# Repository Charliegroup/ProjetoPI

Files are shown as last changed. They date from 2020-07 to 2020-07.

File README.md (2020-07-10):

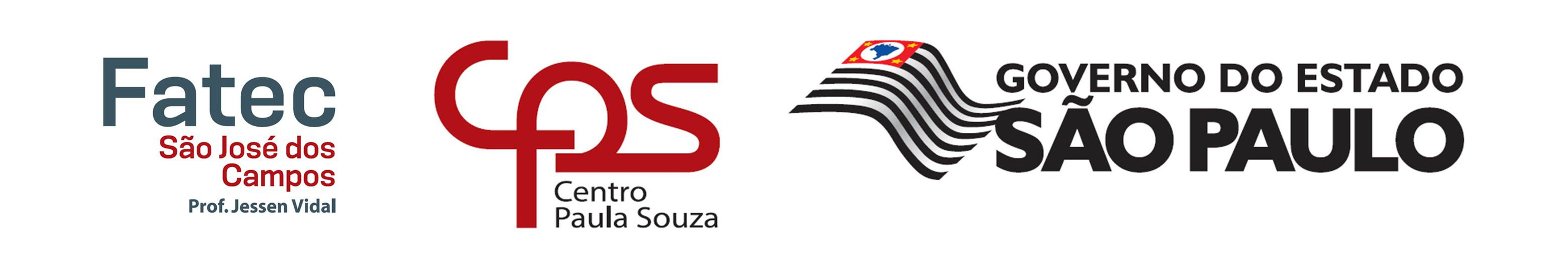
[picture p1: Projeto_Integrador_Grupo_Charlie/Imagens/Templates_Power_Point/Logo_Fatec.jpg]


# Projeto Integrador 4.0 - Fatec São José dos Campos

# - 📁 Descrição das Pastas

* ### Apresentações 
             ➥ Contém as apresentações desenvolvidas pelo grupo;
* ### Atas 
             ➥ Contém as ATAS desenvolvidas durante o projeto;
* ### CAD 
             ➥ Contém os projetos 3D e 2D das peças feitas no CATIA V5;
* ### Cálculos 
             ➥ Contém os cálculos aplicados e utilizados no projeto;
* ### Documentos
             ➥ Contém documentações importantes do projeto;
* ### Imagens
             ➥ Contém todas imagens e templates referentes ao projeto;

# - 📚 Disciplinas integradas

* ### Projeto Integrador 
  Prof. Alexandre Zaramela
* ### Familiarização Aeronáutica 
  Prof. Felix Arlindo Strottmann
* ### Desenho Técnico de Aeronaves
  Profª. Fabiana Eloisa Passador
* ### Informática Aplicada a Aeronáutica
  Prof. Fabrício Galende Marques de Carvalho
* ### Inglês
  Prof. Nilo Jeronimo Vieira
* ### Comunicação Oral e Escrita
  Profª. Maria Goreti Lopes Cepinho
* ### Cálculo Aplicado a Aeronáutica
  Profª. Danielle Cristina de Morais Amorim
* ### Física e Quimica Aplicada a Aeronáutica
  Profª. Danielle Cristina de Morais Amorim
* ### Meio Ambiente, Saude e Seguranca no Trabalho
  Prof. Joares Lidovino dos Reis
* ### Legislação Social Aplicada a Aeronáutica
  Profª. Ana Cecília Rodrigues Medeiros

# - 👥 Grupo: 

* ### Ricardo Donizeti dos Santos - Líder/ Projetista
* ### Paulo Rafael Ribeiro - Vice Líder/ Anotador
* ### Thiago dos Reis Souza - Gestor/ Atas e diário e bordo

# - ✈ Objetivo:

Desenvolver uma ferramenta para desmontagem e/ou instalação do Cilindro do motor Turbo Hélice IO-360-N1A, da Aeronave Embraer EMB-120.
⠀⠀⠀⠀⠀⠀⠀⠀⠀⠀⠀⠀⠀⠀⠀⠀⠀⠀⠀⠀⠀⠀⠀⠀⠀⠀⠀⠀⠀⠀⠀⠀⠀⠀⠀⠀⠀⠀⠀⠀⠀⠀⠀⠀⠀⠀⠀⠀⠀⠀⠀⠀⠀⠀⠀⠀⠀⠀⠀⠀⠀⠀⠀⠀⠀⠀⠀⠀⠀⠀⠀⠀⠀⠀⠀⠀⠀⠀⠀⠀⠀⠀⠀⠀⠀⠀⠀⠀⠀⠀⠀⠀⠀⠀
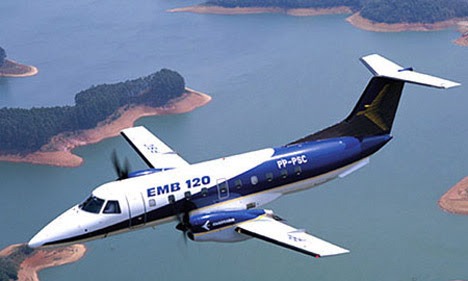
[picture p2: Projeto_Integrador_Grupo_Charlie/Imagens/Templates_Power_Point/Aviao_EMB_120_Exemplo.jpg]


# - 🔧 Ferramentas:
⠀⠀⠀⠀⠀⠀⠀⠀⠀⠀⠀⠀⠀⠀⠀⠀⠀⠀⠀⠀⠀⠀⠀⠀⠀⠀⠀⠀⠀⠀⠀⠀⠀⠀⠀⠀⠀⠀⠀⠀⠀⠀⠀⠀⠀⠀⠀⠀⠀⠀⠀⠀⠀⠀⠀⠀⠀⠀⠀⠀⠀⠀⠀⠀⠀⠀⠀⠀⠀⠀⠀⠀⠀⠀⠀⠀⠀⠀⠀⠀⠀⠀⠀⠀⠀⠀⠀⠀⠀⠀⠀⠀⠀⠀
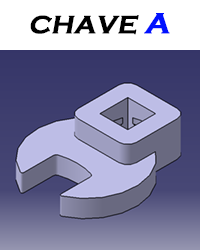
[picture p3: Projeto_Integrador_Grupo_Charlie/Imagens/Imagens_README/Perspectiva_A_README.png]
⠀⠀⠀⠀⠀⠀⠀⠀⠀
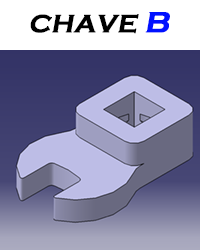
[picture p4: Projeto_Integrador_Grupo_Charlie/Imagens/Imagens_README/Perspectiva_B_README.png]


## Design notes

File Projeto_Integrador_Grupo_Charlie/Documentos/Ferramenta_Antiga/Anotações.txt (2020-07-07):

Tem que o termostato entre 90 e 130 graus

Ferramentas padrões

antes de desmontar tem que despressurizar (retirar a graxa ou o oleo), removendo as valvulas 3/10 e 3/20

remover os tubos flexiveis 2/20 e 2/30

remover os tubos rigidos 3/100

afroxar a porca 3/80 para remover a pressao e remover o cotovelo 3/90

afroxar a porca 3/150 para remover a junção 3/140

remover o tubo de suporte 3/110

afroxar os 4 parafusos 3/120

mantenha as 4 arruelas 3/130

mantenha a abraçadeira 3/110 e (rolamento, cilindro) 3/160

remover separador 3/200

afroxar a porca 3/210

manter arruela 3/220 o pino 3/230 manter equipado o rolamento 3/170

remover as duas buxas 3/190(buxas precisam ser desmontadas numa temperatuxa maxima de 100º)

		Como retirar esta na pagina 301

B ----- 

remover o descarregador estatico 3/590

	remover parafuso 3/600 manter as arruelas 3/6i0 e depois remover o descarregador estatico
	
C -----

remover o "Arm torque" 3/460

	remover "fita" 3/400
		remover as 6 porcas 3/480 e o tubo 3/410, deixar a 6 arruelas 3/490 e as 3/420
		remover os 4 "collars" 3/440 e deixar os 6 parafusos 3/500, 3/510 e 3/450
		deixar os 4 flanger 3/430 e o bonding strip 3/400
	Remover com a ferramenta 50381 os dois pinos 3/520 e 3/530 segurando o "holding the arm torque"

D ----- 

desmontar arm torque

	remover o separador 5/100, destravar e remover a porca 5/110 e mantenha loking whaser 5/120 e arruela de ajuste 5/130
	usar a dural drift e um martelo para remover o pino 5/140
	separar as duas metades do "arm torque" 5/10 e 5/50 e manter a ball joint cage 5/160 e as duas metades da ball joint 5/180
	em cima da arm torque remover as porcas 3/550 e mantenha  as duas arruelas 3/560 e 3/570 e os parafusos 3/580. Libere o tipe guide 3/540

remover as seis buchas 5/30, 5/40 e 5/70 e a ball joint cage 5/80 (figura 302)
	Desmontar numa temperatura de 100ºC e evitar impacto pois pode danificar
	- duas buchas 5/40 usar dural drif 
	- as 4 buchas 5/30 e 5/70 e ball joint cage 5/80 usando o dural tapered drift
	
	PAGINA 304

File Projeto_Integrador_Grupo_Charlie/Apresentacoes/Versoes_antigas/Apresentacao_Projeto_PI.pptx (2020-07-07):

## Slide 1

FATEC SJC

Prof. Cliente: Felix Strottmann
Prof. Orientador: Alexandre Zaramela

Projeto integrador transversal:

Nomes dos integrantes:

• PAULO RAFAEL
• RICARDO DONIZETI
• THIAGO REIS

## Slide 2

FERRAMENTA

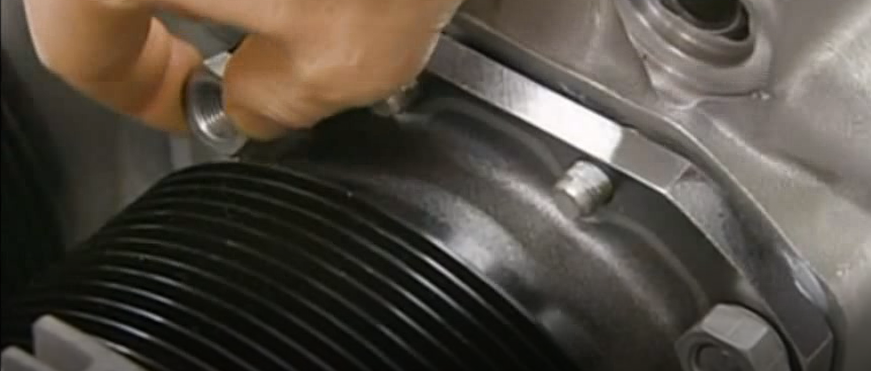
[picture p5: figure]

Soquete para Torquímetro

- Montagem do Piston Ring Compressor ( Fixação da base do cilindro).
- Aperto de porca

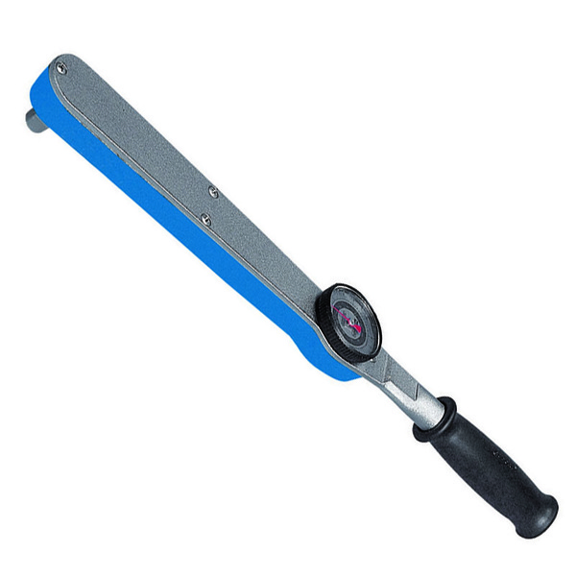
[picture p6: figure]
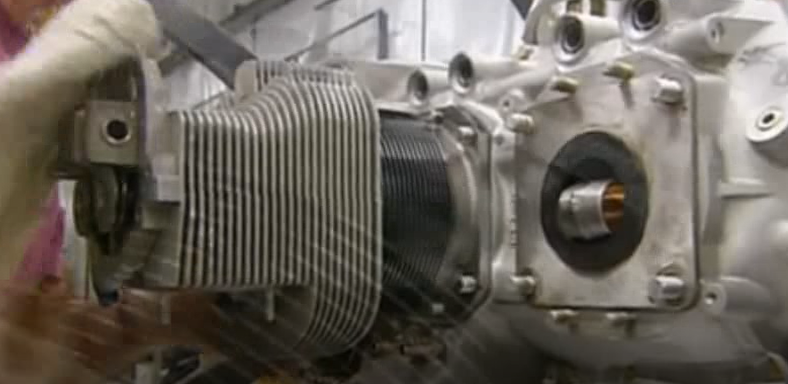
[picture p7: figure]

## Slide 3

COMPARAÇÕES

Primeiro desenho apresentado

Ferramenta proposta

Croqui atual

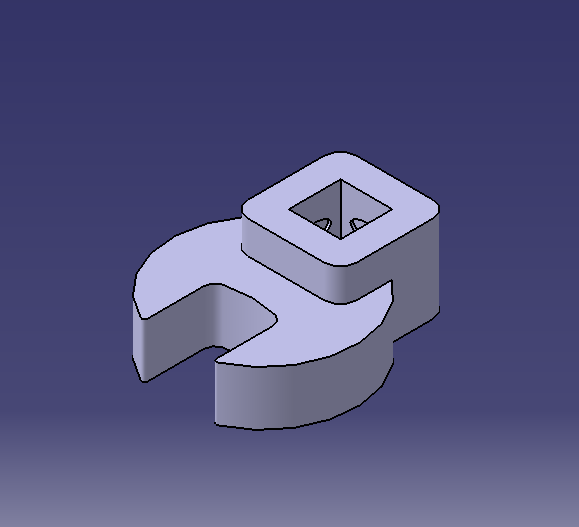
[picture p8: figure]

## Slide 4

COTAS

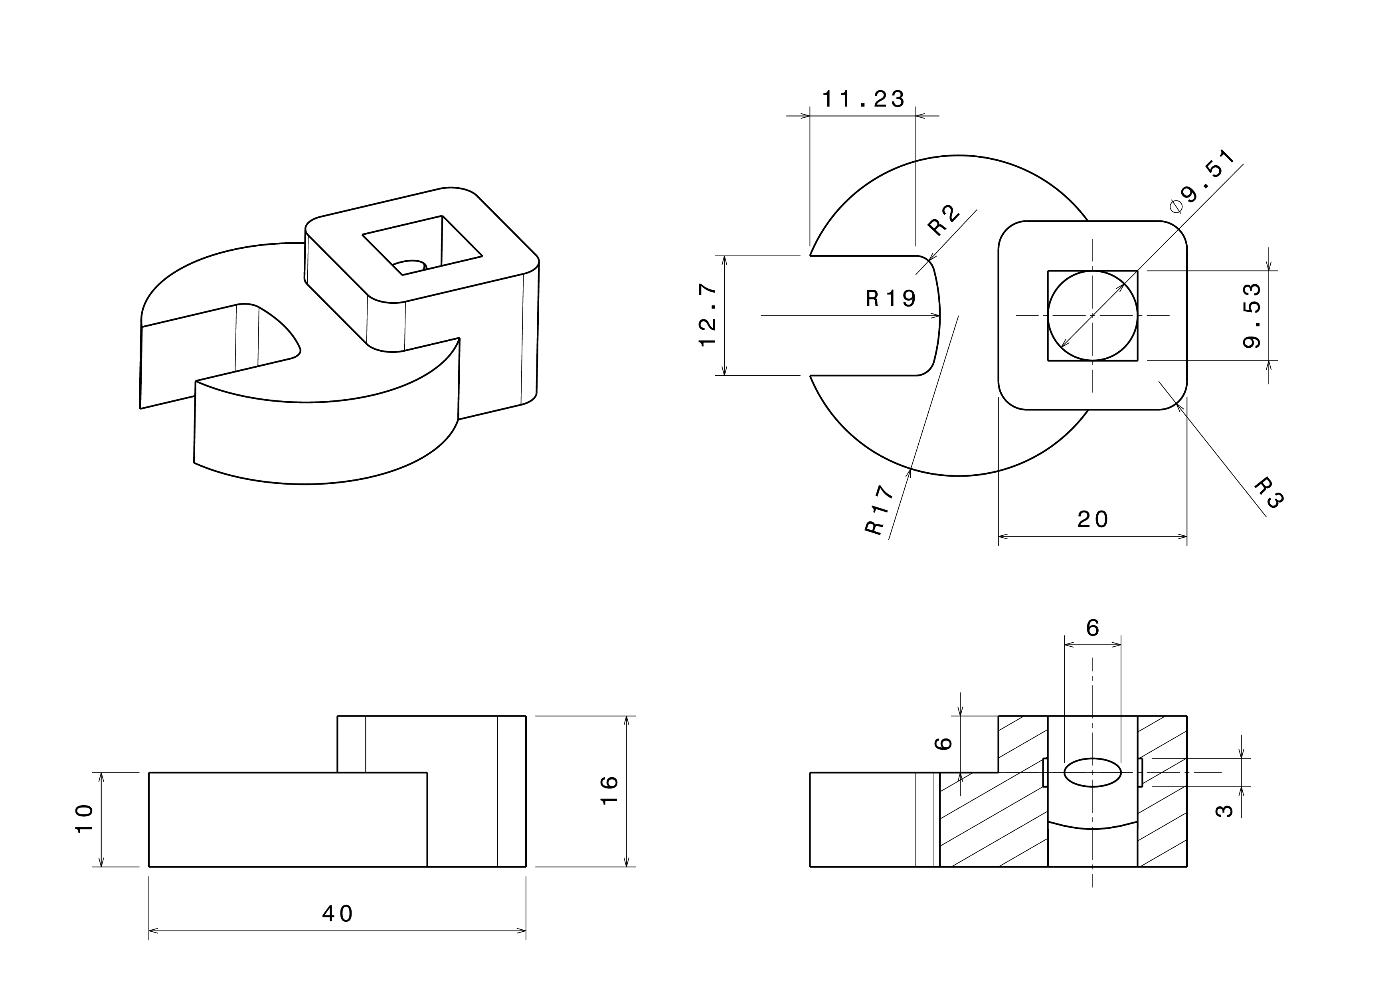
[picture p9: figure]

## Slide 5

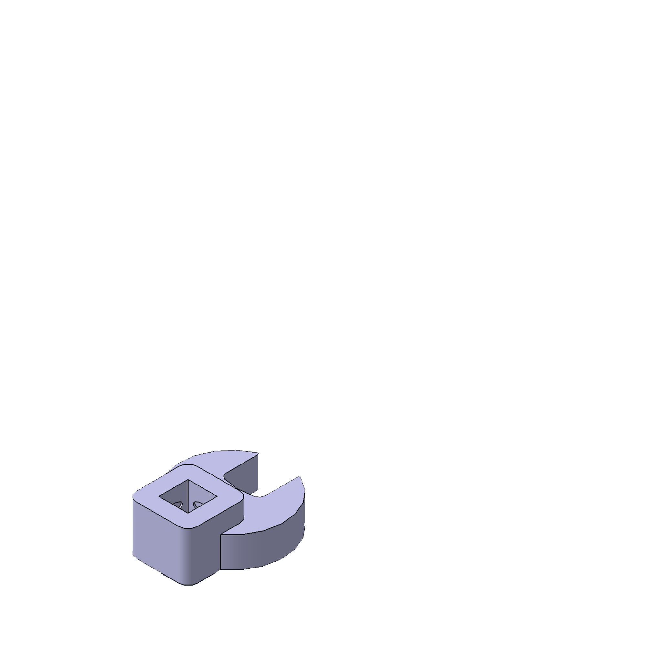
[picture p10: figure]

FERRAMENTA EM PERSPECTIVA

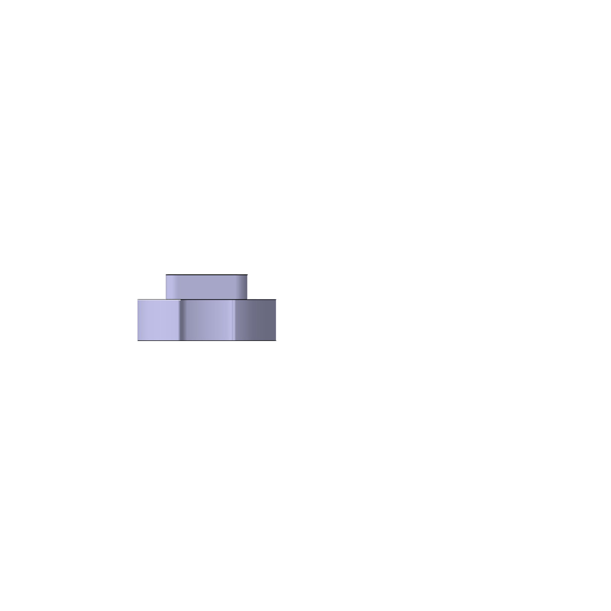
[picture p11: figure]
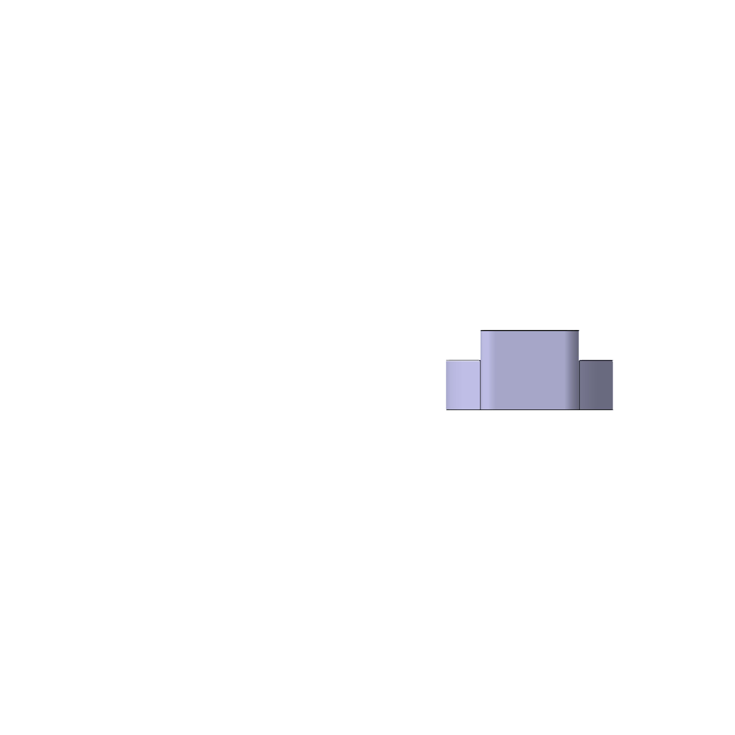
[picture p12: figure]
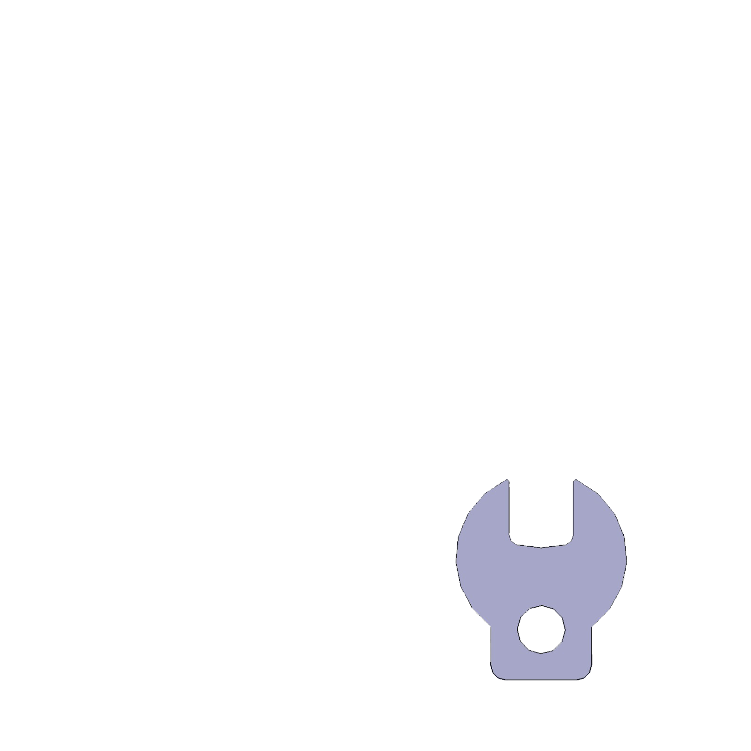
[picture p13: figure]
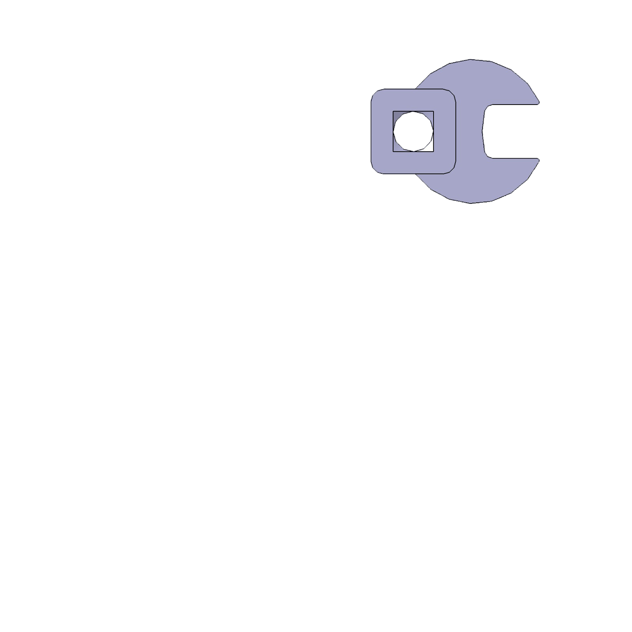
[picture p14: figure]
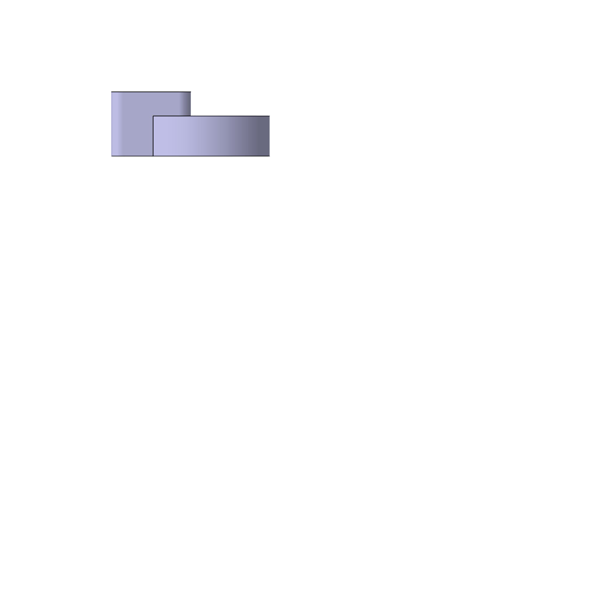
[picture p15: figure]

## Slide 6

CÁLCULO DE TENSÃO DE
CISALHAMENTO

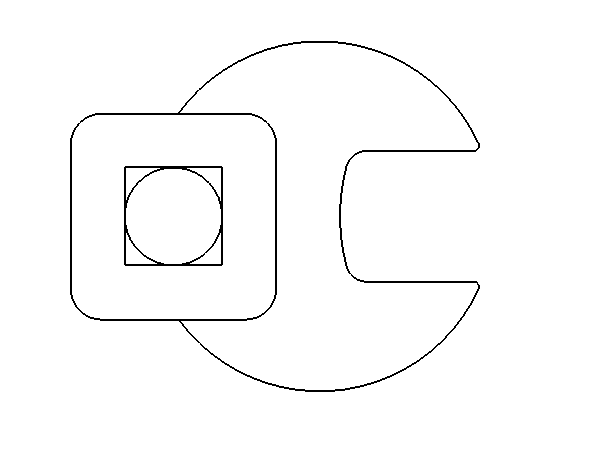
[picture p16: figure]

Força: 67.8 Nm

[Área: 10x

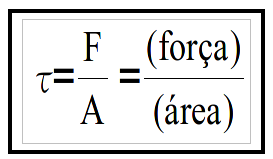
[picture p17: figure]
MINHA CIÊNCIA É FARMACÊUTICA: REOLOGIA: Noções Básicas

T = Torque (Nm)

t = Tensão (N/mm²)

F = Força (N)

A = Área (m²)

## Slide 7

MARGEM DE SEGURANÇA

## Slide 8

PROPRIEDADES “MATERIAL”

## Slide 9

REFERÊNCIAS

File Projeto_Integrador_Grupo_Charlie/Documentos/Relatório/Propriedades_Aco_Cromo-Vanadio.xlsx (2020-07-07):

 | Propriedades
Densidade (×1000 kg/m3) |  | 7.7-8.03
Coeficiente de Poisson |  | 0.27-0.30
Módulo de Elasticidade (GPa) |  | 190-210
Resistência à Tração (Mpa) |  | 670
Tensão de Escoamento (Mpa) |  | 415
Alongamento (%) |  | 23.0
Área de Redução (%) |  | 48.4
Dureza (HB) |  | 197
Força de Impacto (J) |  | 27.4

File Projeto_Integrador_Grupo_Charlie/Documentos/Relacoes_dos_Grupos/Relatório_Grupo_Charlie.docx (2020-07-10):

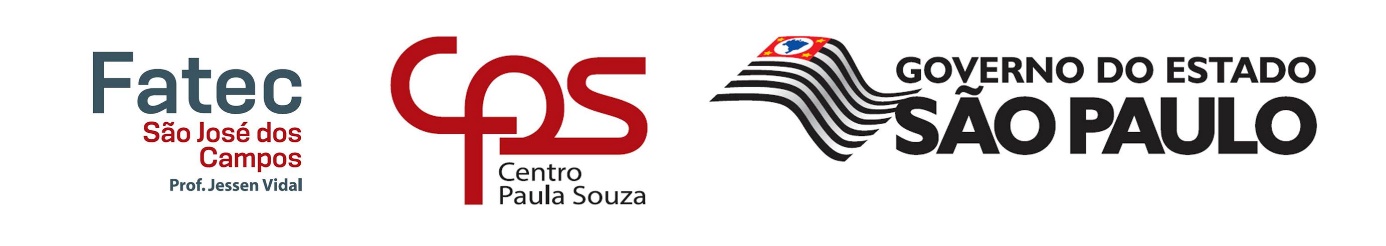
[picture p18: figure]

FATEC – FACULDADE DE TECNOLOGIA DE SÃO JOSÉ DOS CAMPOS
PROF. JESSEN VIDAL

Crows Foot Socket (Soquete Pé de Galinha)

SÃO JOSÉ DOS CAMPOS / SP

1° Semestre - 2020

Crows Foot Socket (Soquete Pé de Galinha), para desmontagem e/ ou instalação do Cilindro do motor Turbo Hélice IO-360-N1A, da Aeronave Embraer EMB-120.

INTEGRANTES: PAULO RAFAEL RIBEIRO, RICARDO DONIZETI DOS SANTOS, THIAGO DOS REIS SOUZA

PROF. ORIENTADOR: ALEXANDRE ZARAMELA

PROF. CLIENTE: FELIX ARLINDO STROTTMANN

CURSO: MANUTENÇÃO DE AERONAVES

SÃO JOSÉ DOS CAMPOS / SP

1° Semestre - 2020

# 1. INTRODUÇÃO

O Projeto Integrador Transversal 4.0 proposto pela FATEC – Faculdade de Tecnologia de São José dos Campos/SP, tem como objetivo proporcionar ao aluno a oportunidade de desenvolvimento de suas habilidades através de um desafio real, que através da prática, o leva a solucionar uma necessidade específica proposta.

No primeiro semestre de 2020, foi proposto para turma de Manutenção de Aeronaves o desafio de projetar cinco (5) ferramentas que serão utilizadas no Laboratório da FATEC para montagem e desmontagem do Cilindro do Motor Turbo Hélice IO-360-N1A e do Atuador do Trem de Pouso Principal do Helicóptero Pantera. A turma foi dividida em cinco (5) grupos e denominados como: Alfa, Bravo, Charlie, Delta e Foxtrot.

O grupo referente a este relatório, Charlie, teve como desafio desenvolver e projetar uma ferramenta para desmontagem e/ ou instalação do Cilindro do Motor Turbo Hélice IO-360-N1A, conforme “IO-360-N1A Engine Maintenance Manual”. A ferramenta em questão tem como objetivo retirar ou colocar as porcas de aperto da base do cilindro.

# 2. MATERIAIS E MÉTODOS

Após apresentação do Projeto Integrador Transversal 4.0 por parte dos professores Félix Arlindo Strottmann e Alexandre Zaramela, os cinco (5) grupos dirigiram-se ao laboratório da FATEC para analisar e tomar nota dos componentes que empregam o uso das ferramentas a serem desenvolvidas. Porém por conta da pandemia muitos grupos tiveram pouco acesso ou não tiveram nenhum acesso aos componentes que que receberia a atuação da ferramenta, como foi o caso do nosso grupo em questão.

Sendo assim observando o componente que receberia atuação da ferramenta “Crows Foot Socket (Soquete Pé de Galinha)” (figura 1), com o auxílio do “IO-360-N1A Engine Maintenance Manual”, obtivemos as medições necessárias para realizar o desenvolvimento proposto, seguindo as informações encontradas na pág. 150 referente a “Base do Cilindro do Motor Turbo Hélice IO-360-N1A” (figura 2).

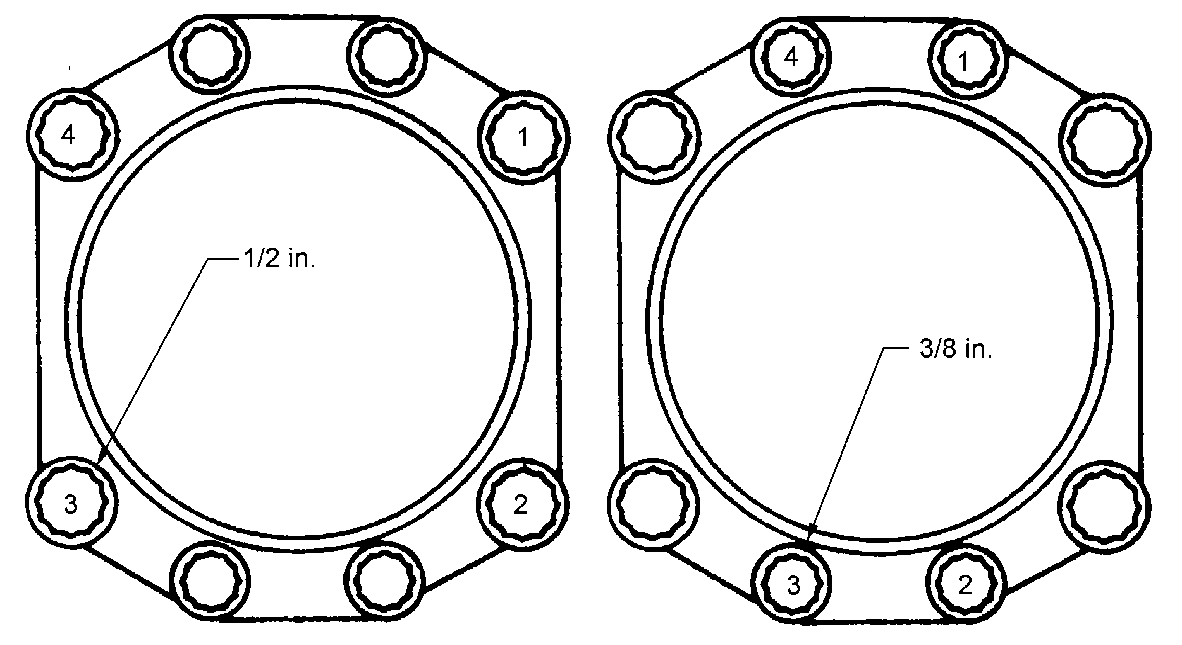
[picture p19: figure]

Em posse das medidas, croquis começaram a ser desenvolvidos a mão e em seguida no software de modelagem CATIA V5.

Os croquis realizados manualmente proporcionaram diversas perspectivas para partir à modelagem virtual da ferramenta no CATIA V5. Durante o desenvolvimento, diversas reuniões ocorreram em grupo e com o auxílio do professor orientador Alexandre Zaramela, realizamos uma melhoria dimensional e estrutural. Abaixo alguns exemplos das dimensões da ferramenta no decorrer do projeto (Figura 3 e 4).

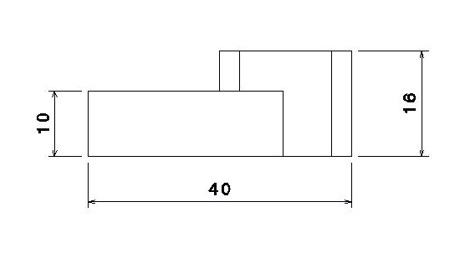
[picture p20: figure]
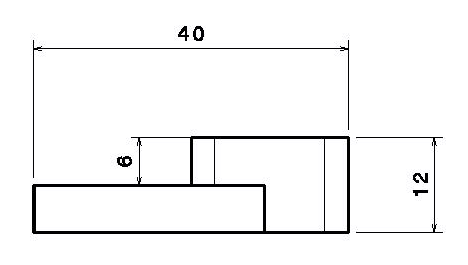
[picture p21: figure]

As seguintes dimensões abaixo, das chaves A (Figura 5) e Chave B (Figura 6), foram definidas para dar início aos cálculos estruturais da ferramenta.

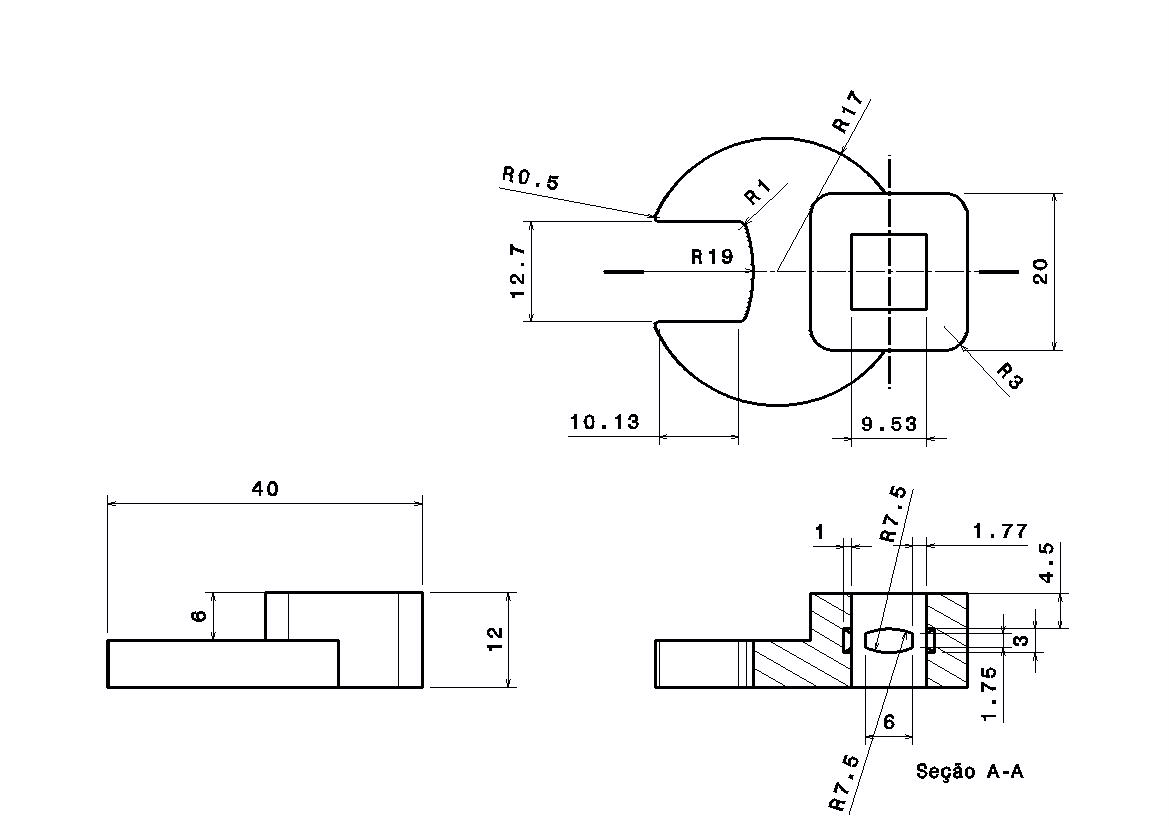
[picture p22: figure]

Figura 5 – Desenho Técnico – Dimensionamento da ferramenta A. Autoria Própria

Figura 6 – Desenho Técnico – Dimensionamento da ferramenta B. Autoria Própria

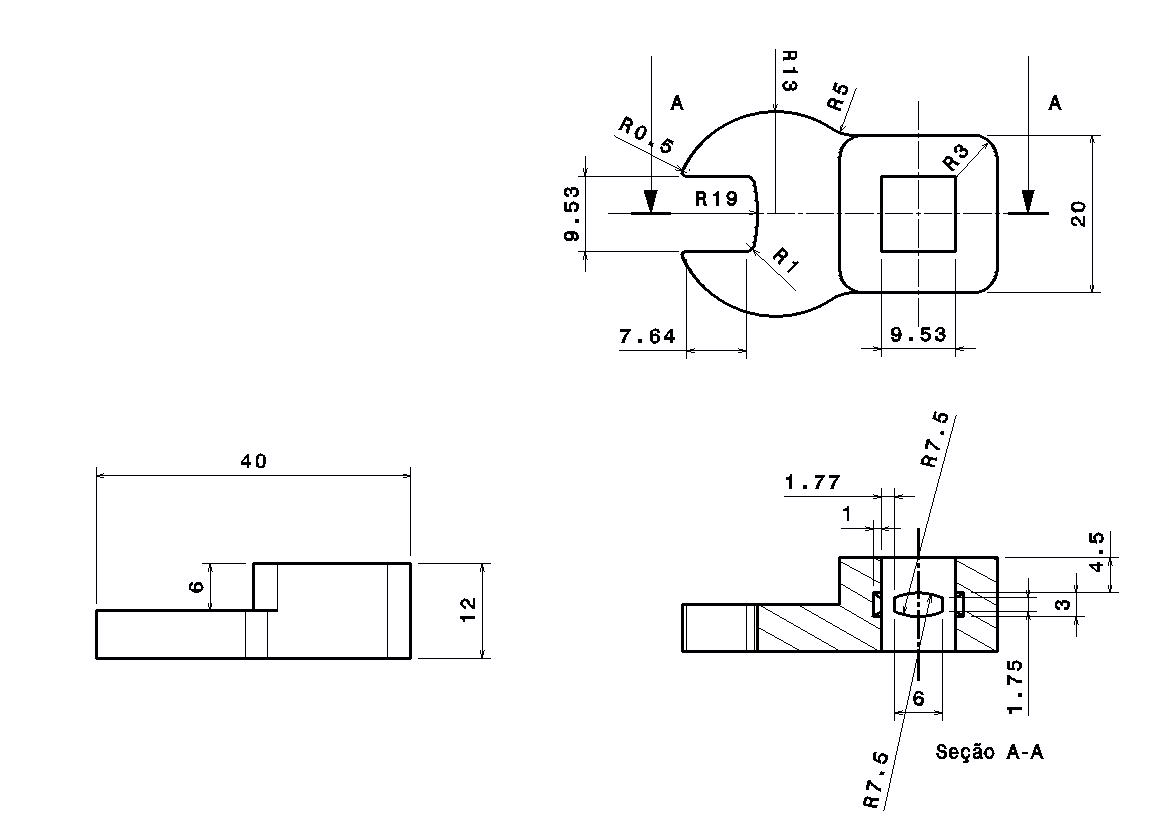
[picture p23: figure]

Quanto a nomenclatura adotada para as chaves, segue figura abaixo.


Figura 7 – Nomenclatura das Chaves

O material escolhido para a ferramenta foi o SAE 6150, Aço Cromo-Vanádio, pois essa liga de aço é a mais utilizada em ferramentas para esforços de torção. O Cromo Vanádio é formado pela combinação de diferentes ligas, que juntas proporcionam propriedades físicas de tolerância a carga, resistência à corrosão e dureza. Não é necessária a aplicação de tratamento, pois as propriedades mecânicas deste material atendem aos esforços que serão demonstrados adiante através dos cálculos com favorável Margem de Segurança.

Propriedades Aço Cromo-Vanádio

Figura 8 – Tabela Aço Cromo Vanádio

# 3. RESULTADOS

## 3.1 Desenvolvimento Analítico

Com as dimensões e o material, foram realizados os seguintes cálculos, nos quais foram desenvolvidos em planilhas eletrônicas, utilizando o Microsoft Excel. Todos os cálculos desenvolvidos no Excel possuem a coloração azul na célula quando é um Input para o cálculo e, dourado para o resultado após aplicação dos Inputs.

1. O cálculo de Tensão de Esmagamento referente a distância onde será calculado a tensão de cisalhamento;
2. Cálculo de Tensão de cisalhamento;
3. Cálculo de Margem de Segurança;

#### 3.1.1 Cálculo de Momento de Força e Tensão de Cisalhamento

O cálculo de Momento de Força entre a ferramenta e as porcas de aperto do cilindro foi realizado para que obtivesse o valor da Tensão de Cisalhamento entre o contato da ferramenta com as porcas de aperto, para posterior avaliação quanto a resistência da ferramenta a este esforço sem deformação permanente. As seguintes equações foram utilizadas:

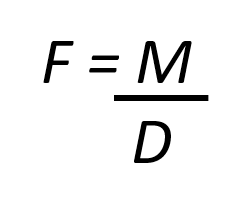
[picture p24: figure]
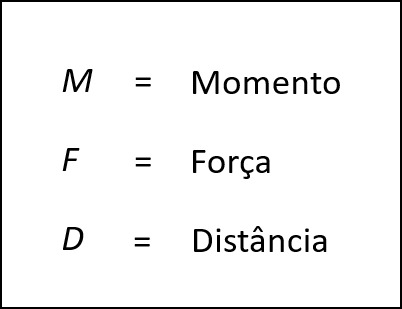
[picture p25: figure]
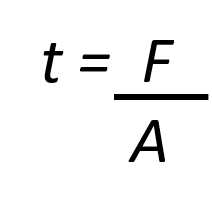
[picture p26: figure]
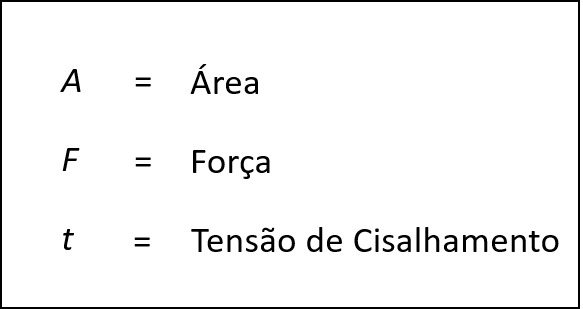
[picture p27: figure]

A Primeira Equação, sendo essa a fórmula do Torque/Momento (Nm), é dada pelo produto da Força em Newtons e “D”, sendo a distância em metros. A Segunda Equação representa o cálculo da Tensão de cisalhamento, sendo “t” a Tensão em (N/mm²) e A a Área em m². Segundo o CMM o Torque de aperto da Chave A é de 67,8Nm e a Chave B 33,9Nm, utilizando as fórmulas e os valores de dimensionamento obteve-se os seguintes resultados:

Cálculo Momento de Força

Chave A

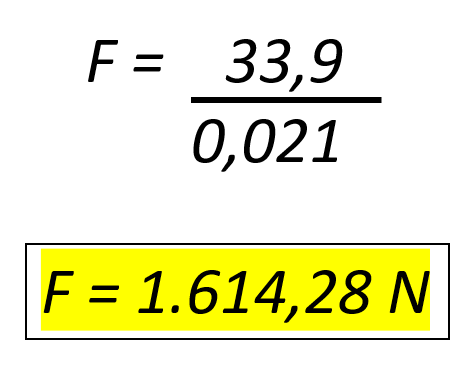
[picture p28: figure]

Chave B

Cálculo de Tensão de Cisalhamento

Chave A


Chave B


#### 3.1.2 Cálculo de Margem de Segurança

Para o cálculo de margem de segurança foi necessário para demonstrar a configuração atual da ferramenta resiste aos esforços nela empregados, define-se como a razão entre a tensão atuante e a tensão de escoamento da peça, subtraído do número inteiro 1 e demonstrado em porcentagem. A seguinte fórmula foi utilizada:


A Equação acima é o cálculo da Margem de Segurança para tensão de escoamento, onde t é a tensão atuante e Fe é a tensão de escoamento do material utilizado, o Aço Cromo-Vanádio. Os seguintes resultados foram obtidos:

Cálculo da margem de segurança.

Chave A


Chave B


3.1.3 Resultado Definitivo

Após a aplicação dos cálculos, obteve-se uma ferramenta capaz de atender aos esforços necessários, com a massa de aproximadamente 52g para Chave A e 46g para Chave B. A Margem de Segurança é bastante satisfatória e, demonstra que a ferramenta é robusta e possui uma ótima otimização.

# 4. CONCLUSÕES

O Projeto Integrador Transversal 4.0 do Primeiro Semestre de 2020 nos trouxe uma situação problema em que teríamos de desenvolver uma ferramenta segundo as necessidades do nosso cliente, planejando, executando e fazendo o controle de eventuais mudanças.

O Projeto deu aos alunos uma oportunidade real de desenvolvimento através da prática, que em consequência, promoveu relacionamento entre cada participante, mostrando o real valor do trabalho em equipe.

A ferramenta atingiu o objetivo que o grupo almejava, tornando todo esforço para a conclusão da mesma como algo muito gratificante.

Todo auxílio que os professores proporcionaram durante o desenvolvimento do projeto foi essencial para o resultado obtido o que garantiu a conclusão do projeto com alto nível de satisfação.

# 5. REFERÊNCIAS

Overhaul Manual – Direct Drive Engine. São Paulo: 2020.

Histórico do Projeto Integrador Transversal, grupo Charlie. Cálculos; Apresentações; ATA; Desenhos Técnicos; Documentos; Repositório do GITHUB. Disponível em: https://github.com/Charliegroup/ProjetoPI – Acesso: 2020.

Aço Cromo Vanádio SAE 6150 – Gerson Luiz, Blog dos Materiais. Propriedades do Aço 6150. Disponível em: https://www.materiais.gelsonluz.com/2017/10/aco-sae-6150-propriedades-mecanicas.html - Acesso em: 2020.

ECIVIL. Descomplicando Engenharia. Módulo de Resistencia. Disponível em: https://
www.ecivilnet.com/dicionario/o-que-e-modulo-de-resistencia.html - Acesso em: 2020.

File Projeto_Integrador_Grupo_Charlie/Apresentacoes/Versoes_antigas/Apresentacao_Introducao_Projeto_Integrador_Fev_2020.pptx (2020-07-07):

## Projeto Integrador – Revisão 01


Programa FATEC 4.0

## Projeto Integrador

Introdução

Professores: Rodrigo e Zaramella
Professor – Cliente: Felix Strottmann

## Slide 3

Projeto Integrador

Projeto de um Ferramenta Especial
para desmontar / montar o cilindro do motor do avião Guri


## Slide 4

Votos de Pleno Êxito
nas Atividades do Projeto Integrador !!

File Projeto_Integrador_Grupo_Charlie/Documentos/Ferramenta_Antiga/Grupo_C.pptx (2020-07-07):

## Grupo C

Componentes:
Paulo Rafael
Thiago reis
Luciano dhelu
Gabriel candido
Ricardo donizeti

## PN OU50402


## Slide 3


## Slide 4


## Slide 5


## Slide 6


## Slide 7


22542K040

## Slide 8


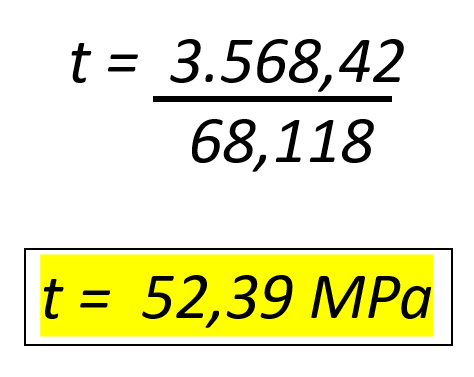
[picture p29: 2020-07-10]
Projeto_Integrador_Grupo_Charlie/Imagens/Imagens_Relatório/Imagem8.png

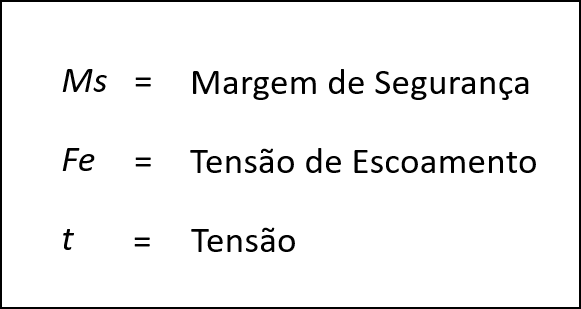
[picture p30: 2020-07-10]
Projeto_Integrador_Grupo_Charlie/Imagens/Imagens_Relatório/Imagem11.png

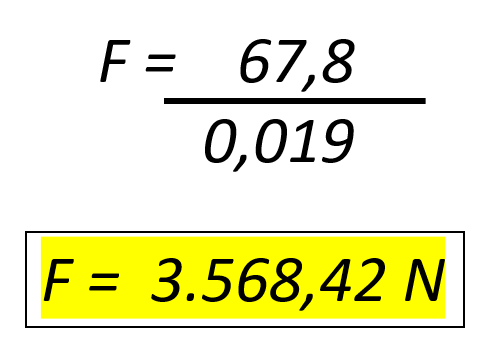
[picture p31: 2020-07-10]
Projeto_Integrador_Grupo_Charlie/Imagens/Imagens_Relatório/Imagem7.png

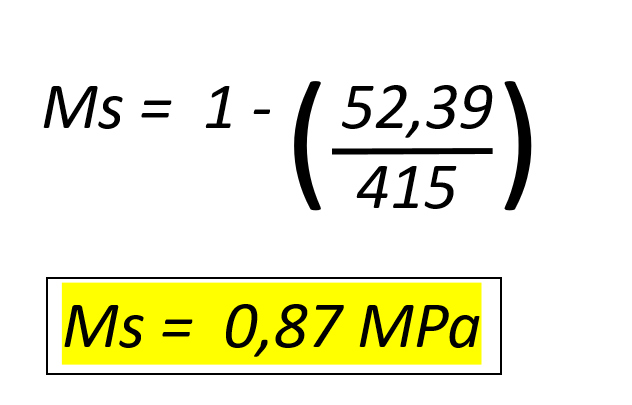
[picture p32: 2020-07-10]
Projeto_Integrador_Grupo_Charlie/Imagens/Imagens_Relatório/Imagem13.png

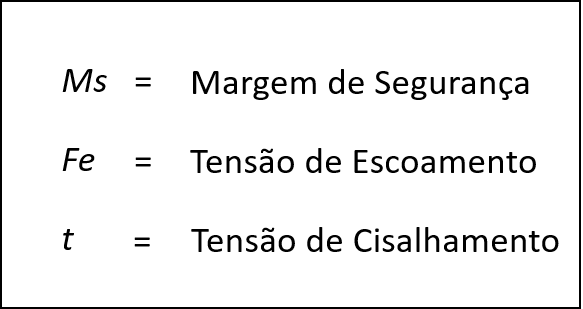
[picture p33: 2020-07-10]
Projeto_Integrador_Grupo_Charlie/Imagens/Imagens_Relatório/Imagem4.png

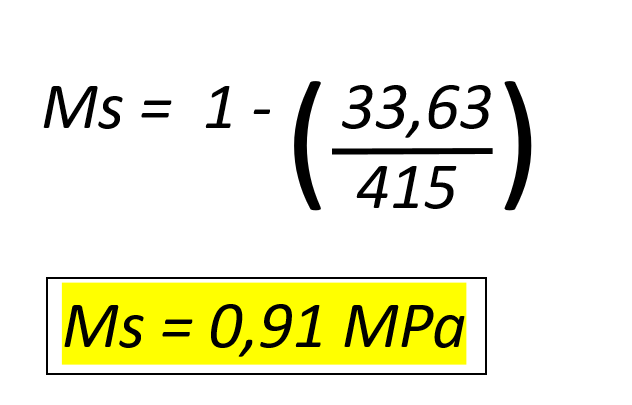
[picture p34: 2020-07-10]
Projeto_Integrador_Grupo_Charlie/Imagens/Imagens_Relatório/Imagem12.png

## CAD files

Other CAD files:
Projeto_Integrador_Grupo_Charlie/CAD/CAD_Final/Chave_A_Final.CATPart
Projeto_Integrador_Grupo_Charlie/CAD/CAD_Final/Chave_B_Final.CATPart
Projeto_Integrador_Grupo_Charlie/CAD/CAD_Testes/Chave_A_30.06.CATPart
Projeto_Integrador_Grupo_Charlie/CAD/CAD_Testes/Chave_A_Final.CATPart
Projeto_Integrador_Grupo_Charlie/CAD/CAD_Testes/Chave_B_30.06.CATPart
Projeto_Integrador_Grupo_Charlie/CAD/CAD_Testes/Chave_PI_CAD1.CATPart
Projeto_Integrador_Grupo_Charlie/CAD/CAD_Testes/Chave_PI_CAD2.CATPart
Projeto_Integrador_Grupo_Charlie/CAD/CAD_Testes/Soquete_meia_polegada.CATPart

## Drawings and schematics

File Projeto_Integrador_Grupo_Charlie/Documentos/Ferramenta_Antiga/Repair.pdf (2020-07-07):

### 18785-200-01 , 18786-200-01 COMPONENT MAINTENANCE MANUAL MAIN LANDING GEAR LEG

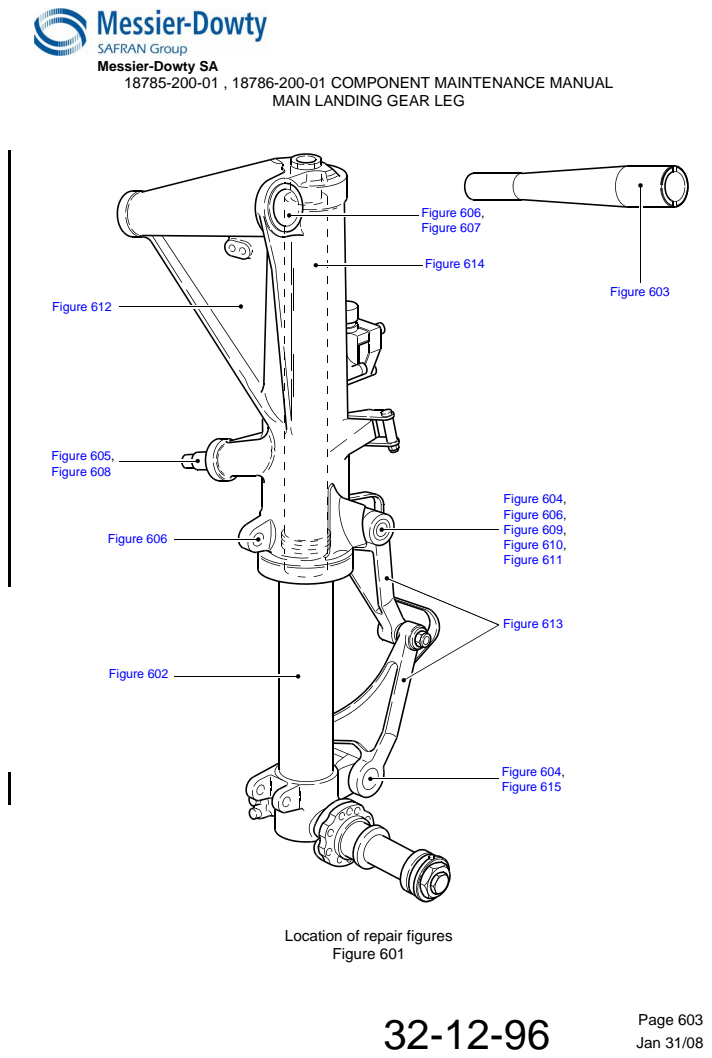
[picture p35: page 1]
Figure 603; Figure 606, Figure 607; Figure 612; Figure 605, Figure 608; Figure 606; Figure 602; Figure 604, Figure 615; Figure 604, Figure 606, Figure 609, Figure 610, Figure 611; Figure 613; Figure 614; Jan 31/08

Messier-Dowty SA

Location of repair figures
Figure 601
Page 603 32-12-96

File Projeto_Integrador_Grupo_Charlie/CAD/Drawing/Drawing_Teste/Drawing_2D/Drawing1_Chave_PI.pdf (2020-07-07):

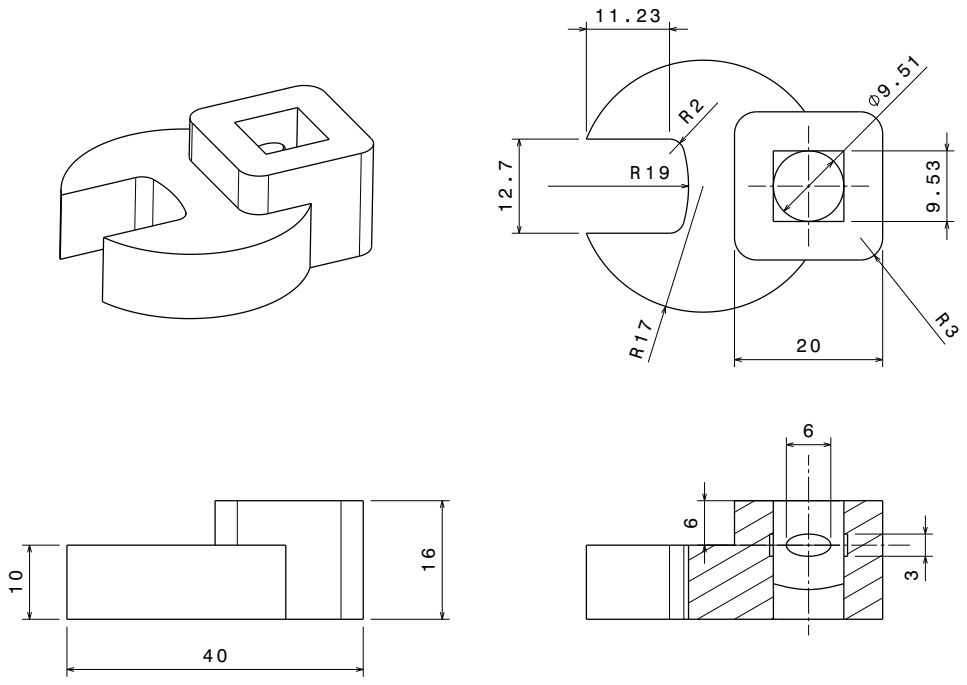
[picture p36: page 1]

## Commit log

2020-07-07 Repositorio Projeto Integrador
    [ATA_Grupo_Chalie.xlsx, Calculos_Chaves_A_e_B_Projeto_Integrador.xlsx, Chave_A_30.06.CATPart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]
2020-07-07 Add README.md
    [Propriedades_Aco_Cromo-Vanadio.xlsx]
2020-07-10 Up de Arquivos Restantes
